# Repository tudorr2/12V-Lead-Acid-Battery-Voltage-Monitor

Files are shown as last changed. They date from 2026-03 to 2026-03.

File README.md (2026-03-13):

# ⚡ 12V Lead Acid Battery Voltage Monitor

<div align="center">








<br/>

_A compact, self-powered PCB module that visually displays the charge level of a 12V lead-acid battery using 10 color-coded LEDs — no external power supply required._

<br/>

---

</div>

## 📖 Table of Contents

- [About the Project](#-about-the-project)
- [Features](#-features)
- [How It Works](#-how-it-works)
- [Components (BOM)](#-components-bill-of-materials)
- [Schematic](#-schematic)
- [PCB Layers](#-pcb-layers)
- [LED Indicator Guide](#-led-indicator-guide)
- [Calibration](#-calibration)
- [PCB Specifications](#-pcb-specifications)
- [Breadboard Prototype](#-breadboard-prototype)

---

## 🔋 About the Project

This project is a **12V Lead-Acid Battery Voltage Monitor** designed as part of a PCB design course.

The monitor provides a clear, instant visual readout of battery voltage through a bar or dot LED display — powered entirely by the battery it monitors. Built around Texas Instruments' **LM3914** analog display driver IC, the design is compact (50×50 mm), low-power, and fully adjustable.

---

## ✨ Features

| Feature | Details |
| --- | --- |
| 🔌 Supply Input | 15 VDC Max |
| 💡 LED Output | 10 LEDs (Bar or Dot mode) |
| 🎛️ Display Modes | BAR (column) / DOT (single LED) via jumper |
| 🔧 Range Adjustment | Min & Max voltage adjustable via onboard presets |
| ⚡ Self-Powered | Draws power directly from monitored battery |
| 🔋 Voltage Range | 10.5V (min) to 15V (max), fully configurable |
| 📏 PCB Size | 50 × 50 mm (square form factor) |
| 🕳️ Mounting Holes | 2× holes (Ø 3.2 mm) on diagonal corners |
| 🔋 Current Draw | Typical ~100 mA |

---

## ⚙️ How It Works

The heart of the circuit is the **LM3914** — a monolithic IC from Texas Instruments that senses an analog voltage and drives up to 10 LEDs in a linear display.

```
Battery (12V DC)
      │
      ▼
   CN1 Header ──► LM3914 (U1)
      │               │
   C1 + C2        10 LED Outputs (D1–D10)
   (filtering)        │
      │           ┌───┴────────┐
   PR2 (MAX)    D1-D3       D4-D8      D9-D10
   PR1 (MIN)   YELLOW       GREEN       RED
   R1, R2
   (reference dividers)
```

1. **Signal Input** — Battery voltage enters via the `CN1` 2-pin Berg connector.
2. **Filtering** — `C1` (10µF/50V) and `C2` (0.1µF) stabilize the supply rail.
3. **Voltage Sensing** — The LM3914's `SIGIN` pin (pin 5) compares the input voltage against an internal precision 10-step resistor ladder.
4. **Reference Calibration** — `PR2` (MAX, ~15V) and `PR1` (MIN, ~10.5V) set the top and bottom of the display range using the `RHI` and `REF ADJ` pins.
5. **LED Drive** — The IC activates the corresponding LED outputs (open-collector, current-regulated) to illuminate the LEDs.
6. **Mode Select** — Jumper `J1` connects pin 9 (MODE) to `V+` for **BAR** mode, or leaves it floating for **DOT** mode.

---

## 🧾 Components (Bill of Materials)

| # | Ref | Description | Value / Part | Qty |
| --- | --- | --- | --- | --- |
| 1 | R1 | Resistor | 4.7KΩ / 0.25W | 1 |
| 2 | R2 | Resistor | 1.2KΩ / 0.25W | 1 |
| 3 | CN1 | Power Connector | 2-Pin Berg Connector | 1 |
| 4 | C1 | Electrolytic Capacitor | 10µF / 50V or 63V | 1 |
| 5 | C2 | Ceramic Capacitor | 0.1µF | 1 |
| 6 | D1, D2, D3 | LED | Yellow, 5mm | 3 |
| 7 | D4–D8 | LED | Green, 5mm | 5 |
| 8 | D9, D10 | LED | Red, 5mm | 2 |
| 9 | U1 | Display Driver IC | LM3914 | 1 |
| 10  | SOCKET | IC Socket | 18-Pin DIP | 1 |
| 11  | PR1, PR2 | Preset Potentiometer | 4.7K/5K | 2 |
| 12  | J1 | Jumper | 2-Pin with closer | 1 |

> 💰 **Estimated total project cost:** ~18–20 RON  
> 🛒 Sources: [Optimusdigital.ro](https://www.optimusdigital.ro), [TME.eu](https://www.tme.eu), [emag.ro](https://www.emag.ro), [electronicmarket.ro](https://electronicmarket.ro)

---

## 📐 Schematic

### Initial Reference Schematic

> The reference schematic used as a starting point for the PCB design:

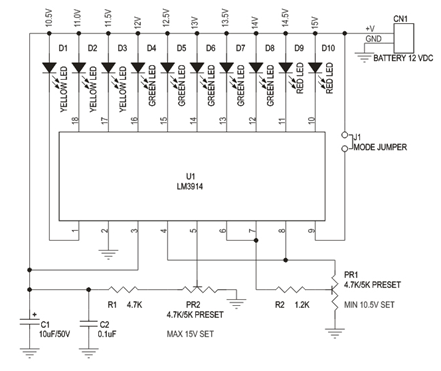
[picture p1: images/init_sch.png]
Initial Schematic
> 

---

### Final CAD Schematic (OrCAD Capture)

> The finalized schematic drawn in Cadence OrCAD:

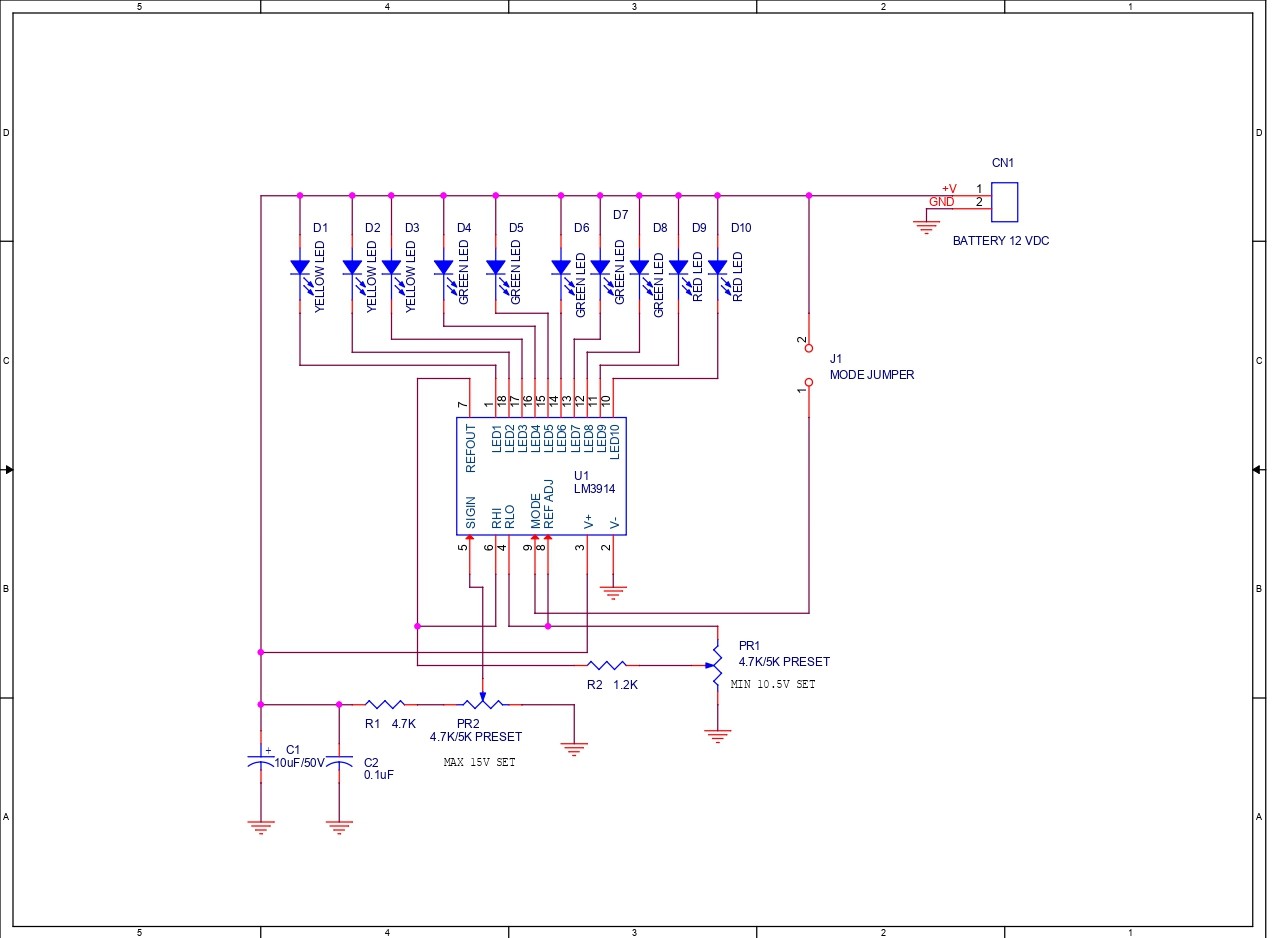
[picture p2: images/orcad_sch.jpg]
CAD Schematic
> 

---

## 🗂️ PCB Layers

The PCB was designed in **Cadence OrCAD PCB Editor 17.2** and exported as Gerber RS-274X files.

### 🟢 Layer TOP (Etch/Top Copper)

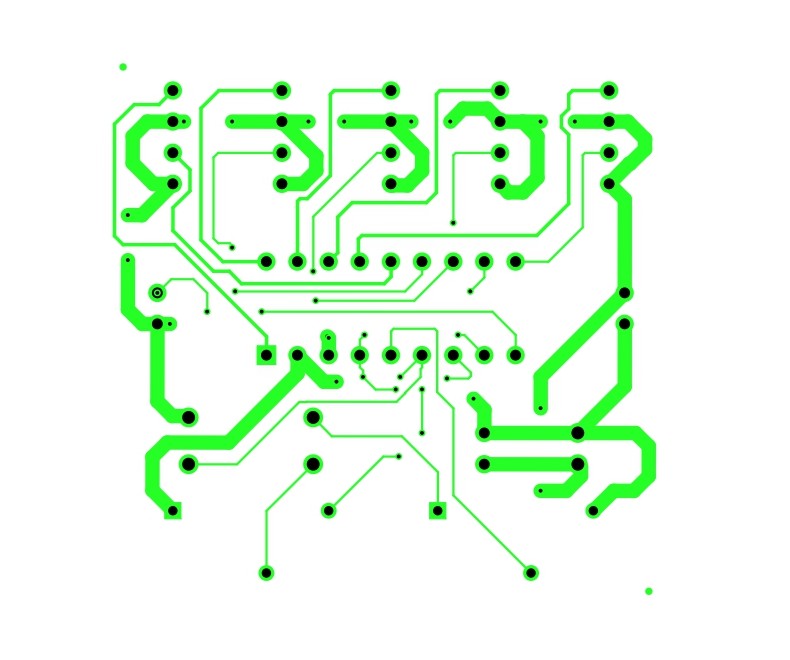
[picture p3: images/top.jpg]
Layer TOP
> 
> _Top copper layer — signal routing_

---

### 🟡 Layer BOTTOM (Etch/Bottom Copper)

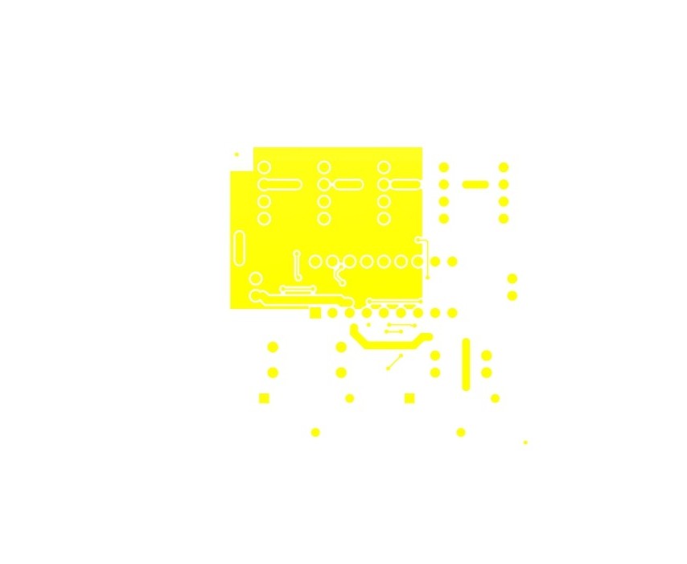
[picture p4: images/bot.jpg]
Layer BOTTOM
> 
> _Bottom copper layer — ground plane and return paths_

---

### 🟫 Layer SOLDER MASK TOP

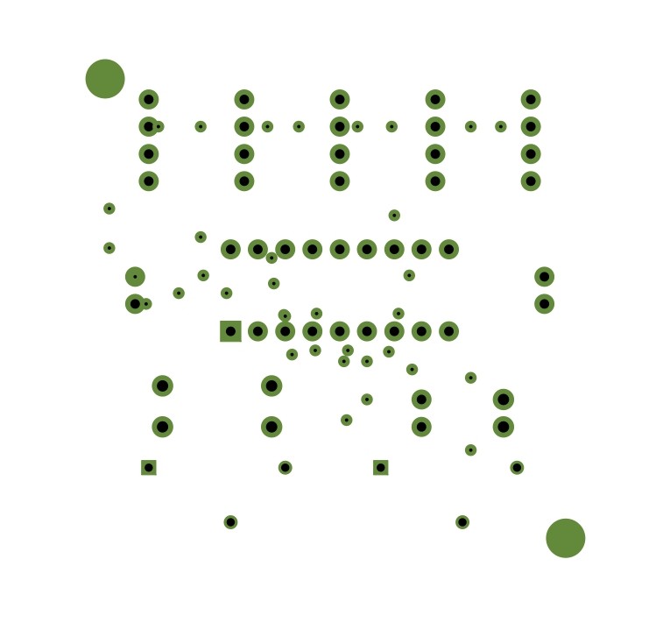
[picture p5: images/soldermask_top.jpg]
Solder Mask TOP
> 
> _Top solder mask — exposes only pads for soldering_

---

### 🟫 Layer SOLDER MASK BOTTOM

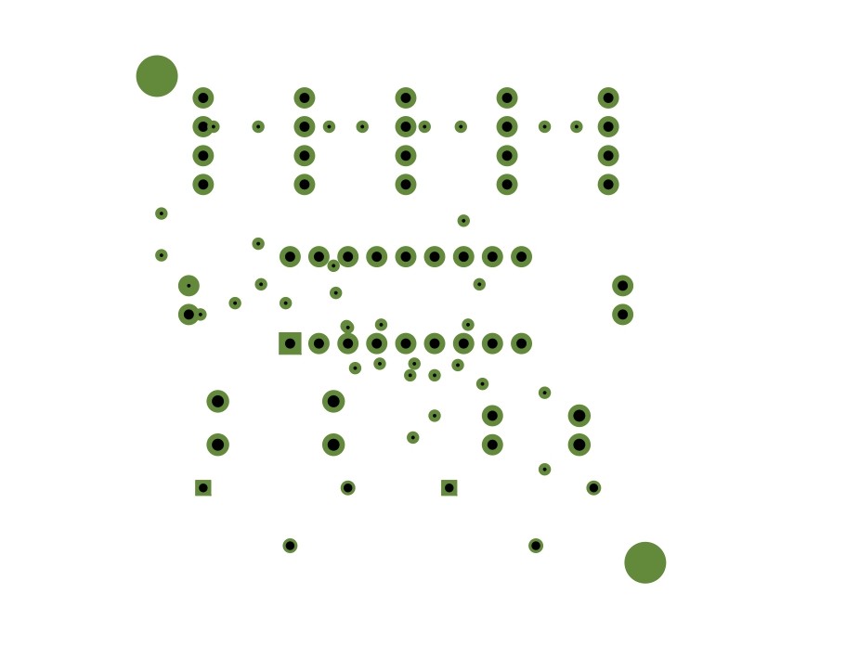
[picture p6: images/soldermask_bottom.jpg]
Solder Mask BOTTOM
> 
> _Bottom solder mask_

---

### 🔵 Layer SILK SCREEN TOP

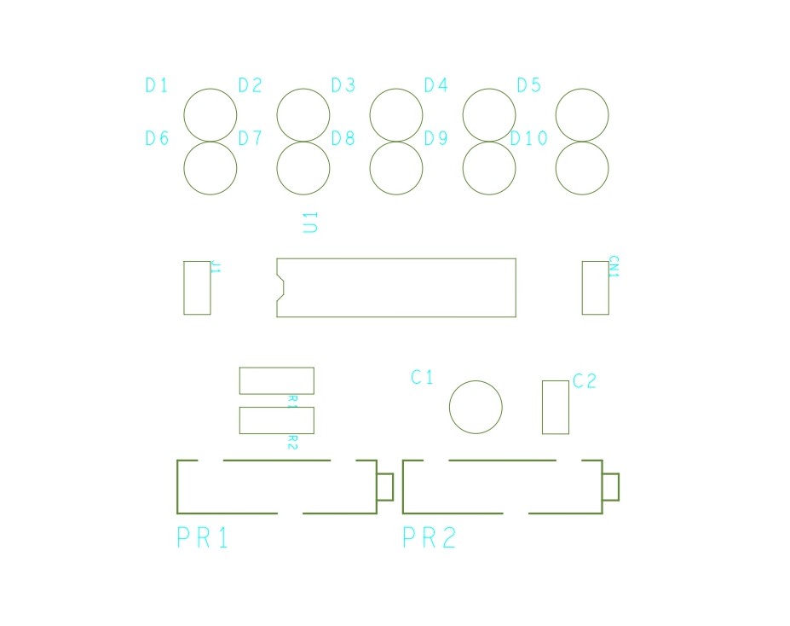
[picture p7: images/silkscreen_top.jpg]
Silkscreen TOP
> 
> _Component reference designators and outlines_

---

### 📋 Layer ASSEMBLY DRAWING TOP

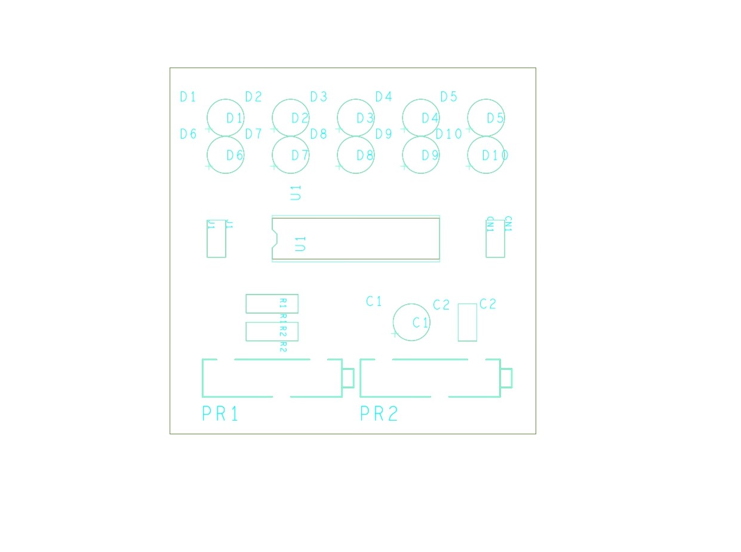
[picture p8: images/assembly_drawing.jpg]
Assembly Drawing
> 
> _Full assembly view showing all component placements_

---

### 🏭 Layer FABRICATION

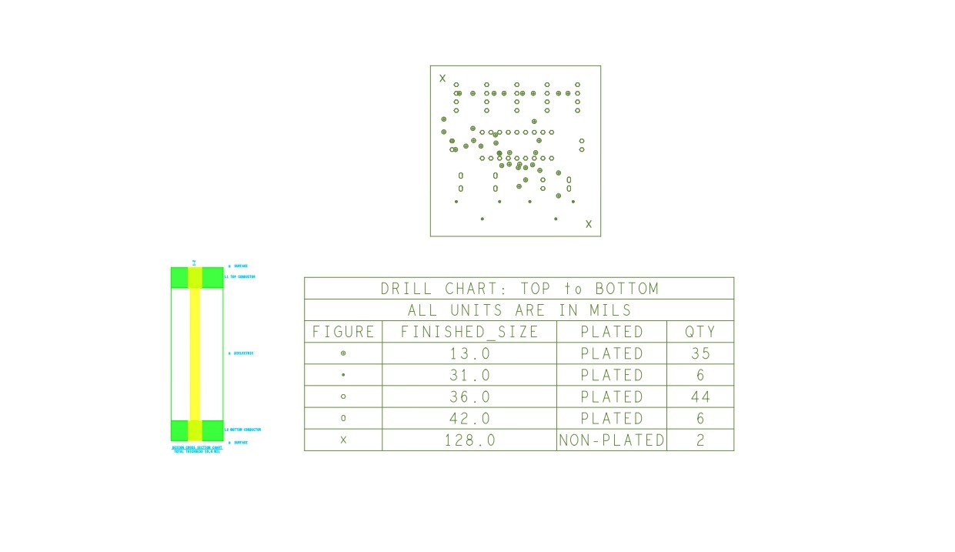
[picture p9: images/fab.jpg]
Fabrication Layer
> 
> _Board outline, dimensions, and drill chart_

**Drill Chart (TOP to BOTTOM):**

| Symbol | Finished Size (mils) | Plated | Qty |
| --- | --- | --- | --- |
| ● | 13.0 | PLATED | 35  |
| ✦ | 31.0 | PLATED | 6 |
| ○ | 36.0 | PLATED | 44  |
| ◌ | 42.0 | PLATED | 6 |
| ✕ | 128.0 | NON-PLATED | 2 |

---

## 💡 LED Indicator Guide

The 10 LEDs are color-coded for instant battery status recognition:

```
  10.5V  11V  11.5V  12V  12.5V  13V  13.5V  14V  14.5V  15V
   D1    D2    D3    D4    D5    D6    D7    D8    D9    D10
  [🟡]  [🟡]  [🟡]  [🟢]  [🟢]  [🟢]  [🟢]  [🟢]  [🔴]  [🔴]
 YELLOW YELLOW YELLOW GREEN  GREEN  GREEN  GREEN  GREEN  RED   RED
```

| Color | LEDs | Voltage Range  | Battery Status |
| --- | --- | --- | --- |
| 🟡 Yellow | D1, D2, D3 | ~10.5V – 11.5V | ⚠️ Low — charge soon |
| 🟢 Green  | D4, D5, D6, D7, D8 | ~12V – 13.5V | ✅ Normal / Optimal  |
| 🔴 Red | D9, D10 | ~14V – 15V | 🔺 High / Overcharge |

**Display Modes (Jumper J1):**

- **BAR mode** `[J1 closed]` — All LEDs from minimum up to current level stay lit (like a fuel gauge)
- **DOT mode** `[J1 open]` — Only the single LED at the current voltage level lights up (lower power consumption)

---

## 🎛️ Calibration

Two onboard trimpots allow field calibration without any extra equipment:

| Preset  | Pin | Function | Default Target |
| --- | --- | --- | --- |
| **PR2** | SIGIN (pin 5) | **MAX voltage** — sets the top of the display range | ~15V |
| **PR1** | REF ADJ (pin 8) | **MIN voltage** — sets the bottom of the display range | ~10.5V |

**Calibration procedure:**

1. Apply a known reference voltage (e.g. 15V) to CN1
2. Adjust **PR2** until only D10 (rightmost LED) lights in DOT mode
3. Apply minimum reference voltage (e.g. 10.5V)
4. Adjust **PR1** until only D1 lights in DOT mode

---

## 📏 PCB Specifications

| Parameter | Value |
| --- | --- |
| Board Shape | Square |
| Dimensions | 50 × 50 mm |
| Mounting Holes  | 2× Ø 3.2 mm |
| Hole Placement  | Diagonal corners, 2M distance from edges |
| Layers | 2 (Top + Bottom copper) |
| Min Track Width | 0.2 mm |
| Min Via Drill | 1.2 mm |
| Min Clearance | 0.35 mm |
| Software | Cadence OrCAD PCB Editor 17.2S025 |
| Output Format | Gerber RS-274X |

---

## 🔬 Breadboard Prototype

> The circuit was first assembled and tested on a breadboard to verify functionality before committing to PCB layout.

<table>
  <tr>
    <td align="center">
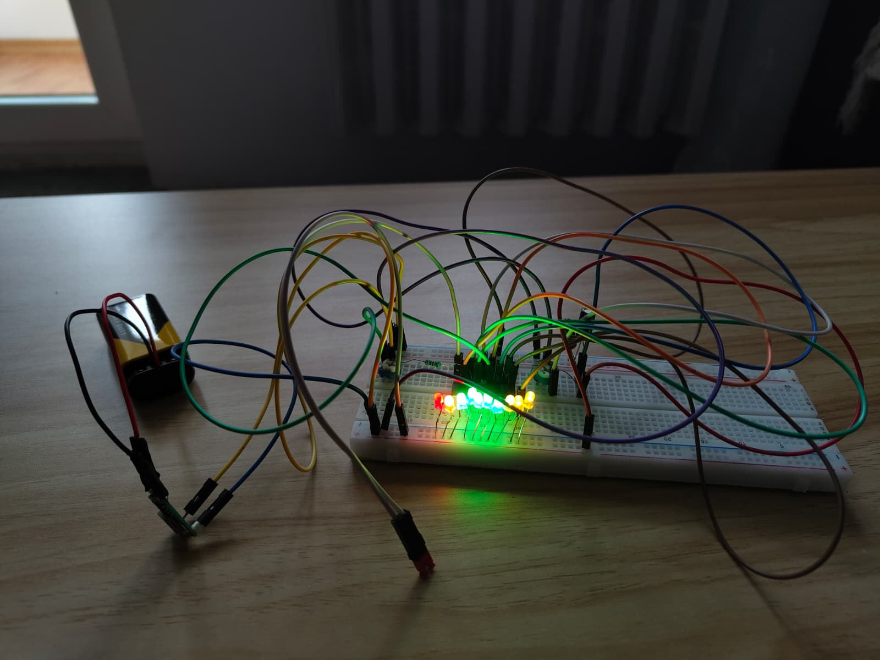
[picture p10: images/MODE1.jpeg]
Breadboard Front
      <br/>
      <sub><b>Bar Mode</b></sub>
    </td>
    <td align="center">
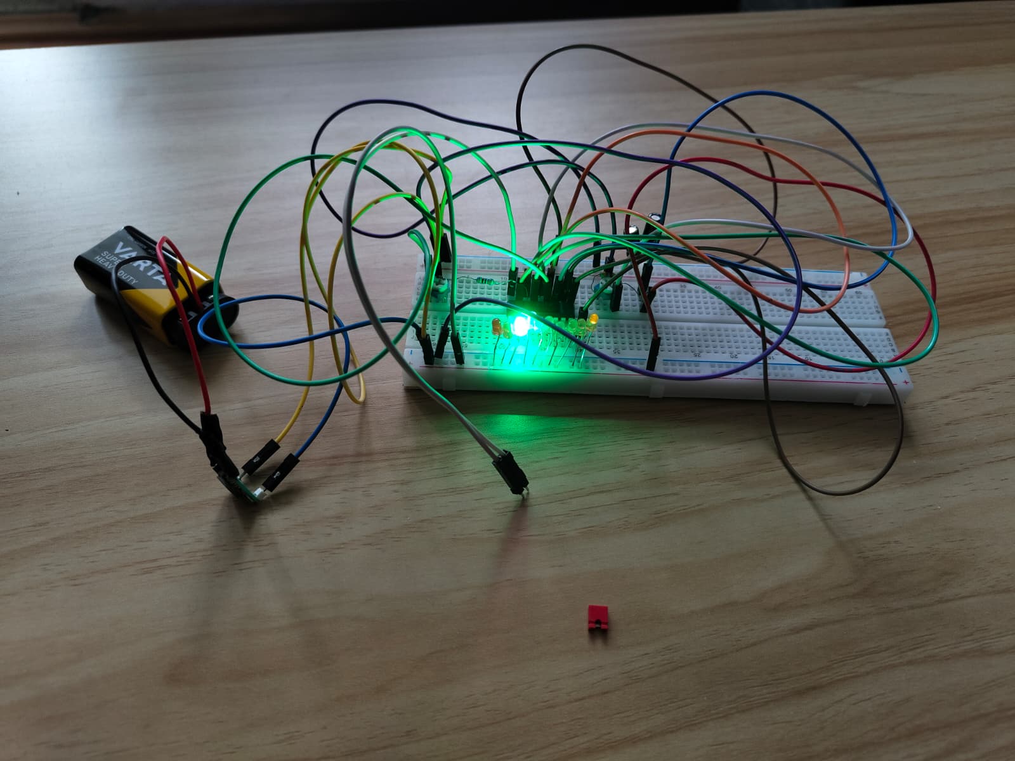
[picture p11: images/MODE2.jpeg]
LEDs Lit
      <br/>
      <sub><b>Dot Mode</b></sub>
    </td>
  </tr>
</table>

---

<div align="center">

_Designed with ❤️ using Cadence OrCAD 17.2 · 2025–2026_

</div>

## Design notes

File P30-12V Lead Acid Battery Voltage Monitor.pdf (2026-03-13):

## 12V Lead Acid Battery Voltage Monitor

Description

12V Lead Acid Battery Monitor is a simple project which tells you the voltage of your Lead acid battery visually with the help of 10 LED’s. This project is based on the popular LM3914 IC from Texas Instruments.

The LM3914 senses the voltage level at the input pin and drives the 10 light emitting diodes based on the voltage detected on input connector. Circuit works on same battery, doesnt not require separate supply input. Jumper is used to select the DOT mode or bar graph mode.

Specifications

- Supply input 15 VDC Max
- Maximum and Minimum range selectable with onboard preset
- Output 10 LED’s
- 2 Types of display Bar and Dot selectable by a jumper
- Very low current consumption, typical 100 mA
- Header connector for connecting power / voltage in
- Four mounting holes of 3.2 mm each
- PCB dimensions 37 mm x 75 mm

Schematic

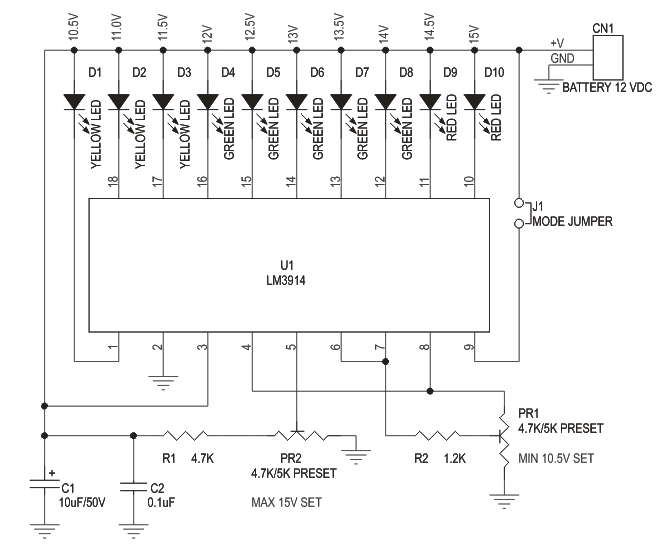
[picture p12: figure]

Parts

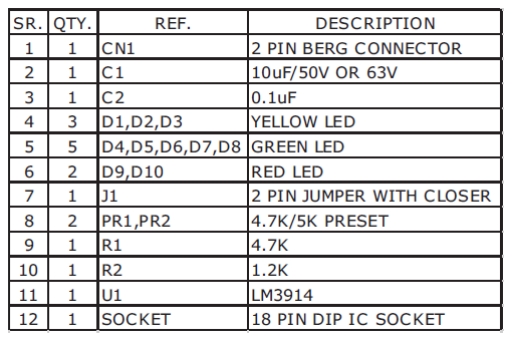
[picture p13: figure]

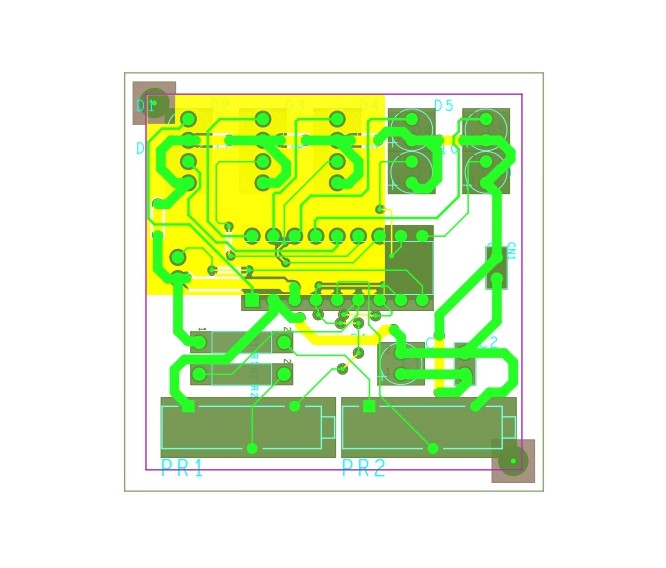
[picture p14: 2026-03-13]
images/schema1.jpg

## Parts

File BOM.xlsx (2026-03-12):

Nr | Referinta comp. în Scm, nume PCB | Tip/Clasa | Descriere | Cod componenta | Producator | Cantitate in proiect | Cantitate minima la distribuitor | Pret/buc (lei) | Pret total componente | Pret total proiect | Site
1 | R1 | 4.7KΩ/0.25W | CFR1 / 4;0.25W ;4.7KΩ;± 5%;2.5 x 6.8 mm | 104210000007381 | optimusdigital | 1 | 1 | 0.1 | 0.1 | 0.1 | https://www.optimusdigital.ro/ro/componente-electronice-rezistoare/849-rezistor-025w-47k.html
2 | R2 | 1.2KΩ/0.25W | T482.1K2;± 5% | T482.1K2 | electronicmarket | 1 | 1 | 0.05 | 0.05 | 0.05 | https://electronicmarket.ro/rezistor-1k2-025-watt
3 | CN1 | 2 PIN BERG CONNECTOR | Conector şiruri pini | ZL201-14G | tme | 1 | 10 | 0.647 | 6.47 | 0.647 | https://www.tme.eu/ro/details/zl201-14g/pini-cu-benzi-si-soclu/connfly/ds1021-1-14sf11-b/?brutto=1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
4 | C1 | 10uF 50V/60V | Condensator Electrolitic de 10 uF la 63 V | 104210000018349 | optimusdigital | 1 | 1 | 0.29 | 0.29 | 0.29 | https://www.optimusdigital.ro/ro/componente-electronice-condensatoare/1880-condensator-electrolitic-de-10-uf-la-63-v.html
5 | C2 | 0.1 uF | Condensator electrolitic 0.1uF 50V | T591.EC0.1UF | Robokit | 1 | 1 | 0.64 | 0.64 | 0.64 | https://robokit.ro/ro/product/0.1uf-50v-condensator-electrolitic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
6 | D1,D2,D3 | Standard Yellow LED | LED-uri galbene 5 mm cu lentile difuze | 104110000045102 | Plusivo | 3 | 20 | 0.089 | 1.78 | 0.267 | https://www.optimusdigital.ro/ro/kituri-optimus-digital/9517-set-de-led-uri-asortate-de-5-mm-si-3-mm-310-buc-cu-rezistoare-bonus.html
7 | D4,D5,D6,D7,D8 | Standard Green LED | LED-uri verzi 5 mm cu lentile difuze | 104110000045102 | Plusivo | 5 | 20 | 0.089 | 1.78 | 0.445 | https://www.optimusdigital.ro/en/leds/13608-set-of-25-leds-5mm.html
8 | D9,D10 | Standard Red LED | LED-uri roșii 5 mm cu lentile difuze | 104110000045102 | Plusivo | 2 | 20 | 0.089 | 1.78 | 0.178 | https://www.optimusdigital.ro/en/leds/13608-set-of-25-leds-5mm.html
9 | U1 | LM3914 | LM3914 DIP18 FV | K366/L(ID46303216) | SuperElektronika | 1 | 1 | 17.93 | 17.93 | 17.93 | https://www.emag.ro/circuit-integrat-driver-led-lm3914-dip18-fv-k366-l/pd/D345NRMBM/
10 | SOCKET | 18 Pin Dip Ic Socket | IC DIP18, SE, 2.54 mm | K457/DIP18(ID186552688) | SuperElektronika | 1 | 1 | 16.56 | 16.56 | 16.56 | https://www.emag.ro/soclu-ic-dip18-se-2-54-mm-k457-dip18/pd/DY7GV5MBM/
11 | PR1 ,PR2 | 4.7K/5K PRESET | Potentiometru Semireglabil 5K | 104110000077820 | optimusdigital | 2 | 1 | 0.99 | 0.99 | 1.98 | https://www.optimusdigital.ro/ro/componente-electronice-potentiometre/11965-potentiometru-semireglabil-5k.html
12 | J1 | 2 PIN JUMPER WITH CLOSER | Pitch: 2.54 mm, 2 Pini | 104210000013498 | optimusdigital | 1 | 1 | 0.18 | 0.18 | 0.18 | https://www.optimusdigital.ro/ro/altele/1522-jumper-de-254-mm-negru-cap-deschis.html
 |  |  |  |  |  |  |  |  | TOTAL | 39.267

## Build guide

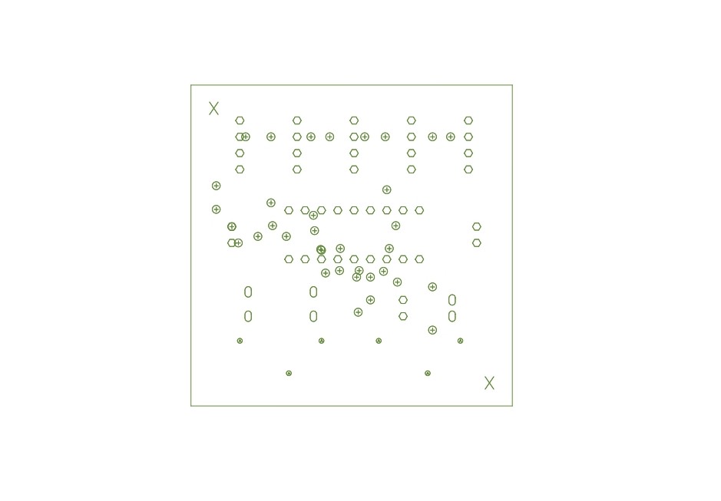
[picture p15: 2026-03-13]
images/fabricationjpg.jpg

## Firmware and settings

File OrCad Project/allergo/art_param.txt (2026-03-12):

DEVICE-TYPE           GERBER_RS274X
OUTPUT-UNITS          INCHES
FILM-SIZE             24000 16000
FORMAT                5.3
ABORT-ON-ERROR        NO
SCALE                 1
SUPPRESS-LEAD-ZEROES  YES
SUPPRESS-TRAIL-ZEROES NO
SUPPRESS-EQUAL        YES
UNDEF-APT-CONT        NO

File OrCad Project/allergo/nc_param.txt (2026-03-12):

INTEGER-PLACES         2
DECIMAL-PLACES         5
X-OFFSET               0.000000
Y-OFFSET               0.000000
FEEDRATE               1
COORDINATES            ABSOLUTE
OUTPUT-UNITS           ENGLISH
TOOL-ORDER             INCREASING
REPEAT-CODES           YES
SUPPRESS-LEAD-ZEROES   NO
SUPPRESS-TRAIL-ZEROES  NO
SUPPRESS-EQUAL         NO
TOOL-SELECT            YES
OPTIMIZE_DRILLING      NO
ENHANCED_EXCELLON      NO
TAPE-FILE              C:/Users/tudor/Desktop/etti an 2 sem 1/ptcad/PTCAD/pcb editor/SCHEMA_1_bun.drl
HEADER                 none
LEADER                 12
CODE                   ASCII
SEPARATE               NO
SEPARATE-ROUTING       NO
DRILLING               LAYER-PAIR
BACKDRILL              NO
CAVITY                 NO
COUNTER                NO
TOLERANCE_DRILL        YES
TOLERANCE_TRAVEL       YES
TOOL_SIZE              YES
ROTATION               YES
NON_STANDARD           YES
TOTAL_DRILL            NO
SEPARATE_SLOT          NO
SUPPRESS_TOLERANCE     YES
SUPPRESS_TOOLSIZE      YES
SUPPRESS_ROTATION      YES
